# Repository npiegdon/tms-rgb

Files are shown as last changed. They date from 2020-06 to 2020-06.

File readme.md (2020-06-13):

# TMS-RGB #

## An RGB mod for systems using TMS9928A and TMS9929A graphics ##

This small adapter board can unlock the potential of many 8-bit systems from the 1980's including the Colecovision, SG-1000, SC-3000, TI-99/4, and more.

This solution introduces zero latency, works in NTSC or PAL systems, doesn't require any tuning, and can be installed easily.  TMS-RGB was developed in 2020 and solves all known issues found in previous TMS992xA mods of this kind.

Visit [https://tms-rgb.com](https://tms-rgb.com) for more information.

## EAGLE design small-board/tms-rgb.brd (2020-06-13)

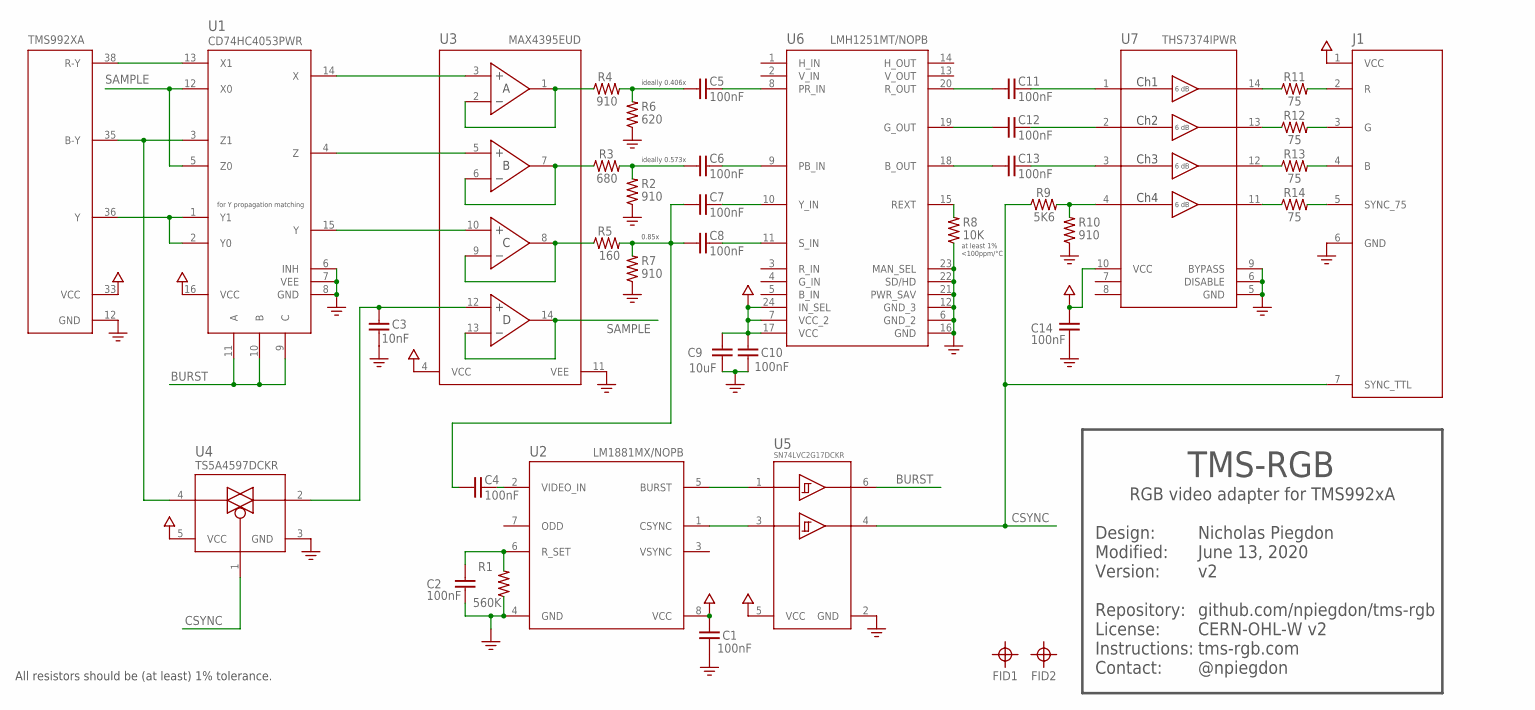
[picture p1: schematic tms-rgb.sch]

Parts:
C1, C2, C4, C5, C6, C7, C8, C10, C11, C12, C13, C14: 100nF; C0603
C3: 10nF; C0603
C9: 10uF; C1206
FID1, FID2: FIDUCIAL
J1: Pads; PADS
R1: 560K; R0603
R2, R4, R7, R10: 910; R0603
R3: 680; R0603
R5: 160; R0603
R6: 620; R0603
R8: 10K; R0603
R9: 5K6; R0603
R11, R12, R13, R14: 75; R0603
U1: CD74HC4053PWR; CD74HC4053
U2: LM1881MX/NOPB; LM1881
U3: MAX4395EUD; MAX4395
U4: TS5A4597DCKR; DCK5
U5: SN74LVC2G17DCKR; DCK6
U6: LMH1251MT/NOPB; LMH1251
U7: THS7374IPWR; THS7374
U100: TMS992XA

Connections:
B: J1.4 (B), R13.2
B-Y: U1.3 (Z1), U4.4 (NC), U100.35 (B-Y)
BURST: U1.9 (C), U1.10 (B), U1.11 (A), U5.6 (1Y)
CSYNC: J1.7 (SYNC_TTL), R9.1, U4.1 (IN), U5.4 (2Y)
G: J1.3 (G), R12.2
GND: C1.2, C2.2, C3.2, C9.2, C10.2, C14.2, J1.6 (GND), R1.1, R2.1, R6.1, R7.1, R8.1, R10.1, U1.6 (INH), U1.7 (VEE), U1.8 (GND), U2.4 (GND), U3.11 (VEE), U4.3 (GND), U5.2 (GND), U6.6 (GND_2), U6.12 (GND_3), U6.16 (GND), U6.21 (PWR_SAV), U6.22 (SD/HD), U6.23 (MAN_SEL), U7.5 (GND), U7.6 (DISABLE), U7.9 (BYPASS), U100.12 (GND)
HOLD: C3.1, U3.12 (D+), U4.2 (COM)
MX_B: U1.4 (Z), U3.5 (B+)
MX_R: U1.14 (X), U3.3 (A+)
MX_Y: U1.15 (Y), U3.10 (C+)
unnamed: R4.1, U3.1 (A), U3.2 (A-)
unnamed: R3.1, U3.6 (B-), U3.7 (B)
unnamed: R5.1, U3.8 (C), U3.9 (C-)
unnamed: U2.5 (BURST), U5.1 (1A)
unnamed: U2.1 (CSYNC), U5.3 (2A)
unnamed: C2.1, R1.2, U2.6 (R_SET)
unnamed: R8.2, U6.15 (REXT)
unnamed: R14.1, U7.11 (CH4OUT)
unnamed: R9.2, R10.2, U7.4 (CH4IN)
unnamed: R13.1, U7.12 (CH3OUT)
unnamed: R12.1, U7.13 (CH2OUT)
unnamed: R11.1, U7.14 (CH1OUT)
unnamed: C4.2, U2.2 (VIDEO_IN)
unnamed: C5.2, U6.8 (PR_IN)
unnamed: C6.2, U6.9 (PB_IN)
unnamed: C8.2, U6.11 (S_IN)
unnamed: C7.2, U6.10 (Y_IN)
unnamed: C11.1, U6.20 (R_OUT)
unnamed: C12.1, U6.19 (G_OUT)
unnamed: C13.1, U6.18 (B_OUT)
unnamed: C11.2, U7.1 (CH1IN)
unnamed: C12.2, U7.2 (CH2IN)
unnamed: C13.2, U7.3 (CH3IN)
R: J1.2 (R), R11.2
R-Y: U1.13 (X1), U100.38 (R-Y)
S75: J1.5 (SYNC_75), R14.2
SAMPLE: U1.5 (Z0), U1.12 (X0), U3.13 (D-), U3.14 (D)
SC_B: C6.1, R2.2, R3.2
SC_R: C5.1, R4.2, R6.2
SC_Y: C4.1, C7.1, C8.1, R5.2, R7.2
VCC: C1.1, C9.1, C10.1, C14.1, J1.1 (VCC), U1.16 (VCC), U2.8 (VCC), U3.4 (VCC), U4.5 (VCC), U5.5 (VCC), U6.7 (VCC_2), U6.17 (VCC), U6.24 (IN_SEL), U7.10 (VCC), U100.33 (VCC)
Y: U1.1 (Y1), U1.2 (Y0), U100.36 (Y)

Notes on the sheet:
Nicholas Piegdon June 13, 2020 v2 github.com/npiegdon/tms-rgb CERN-OHL-W v2 tms-rgb.com @npiegdon
Design: Modified: Version: Repository: License: Instructions: Contact:
RGB video adapter for TMS992xA
TMS-RGB
at least 1% <100ppm/°C
All resistors should be (at least) 1% tolerance.
for Y propagation matching
ideally 0.406x
ideally 0.573x
0.85x

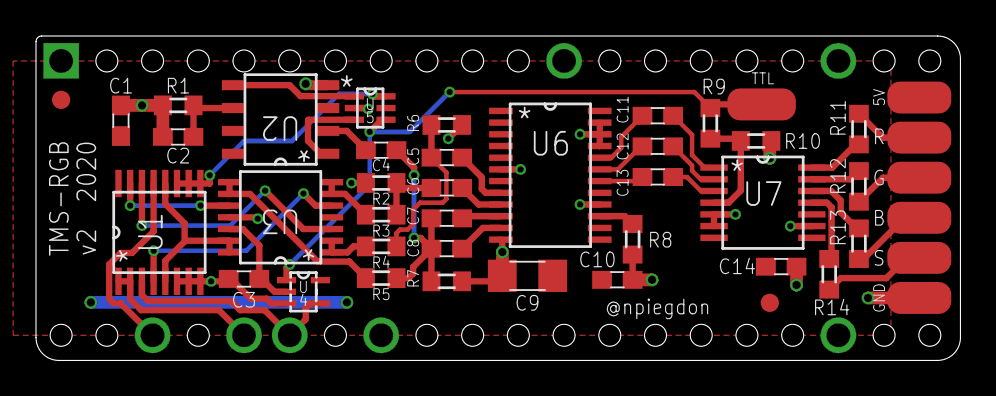
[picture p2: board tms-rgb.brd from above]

Board: 2 copper layers, 51.4 x 18.0 mm, 39 parts (1 on the bottom side), 42 nets.

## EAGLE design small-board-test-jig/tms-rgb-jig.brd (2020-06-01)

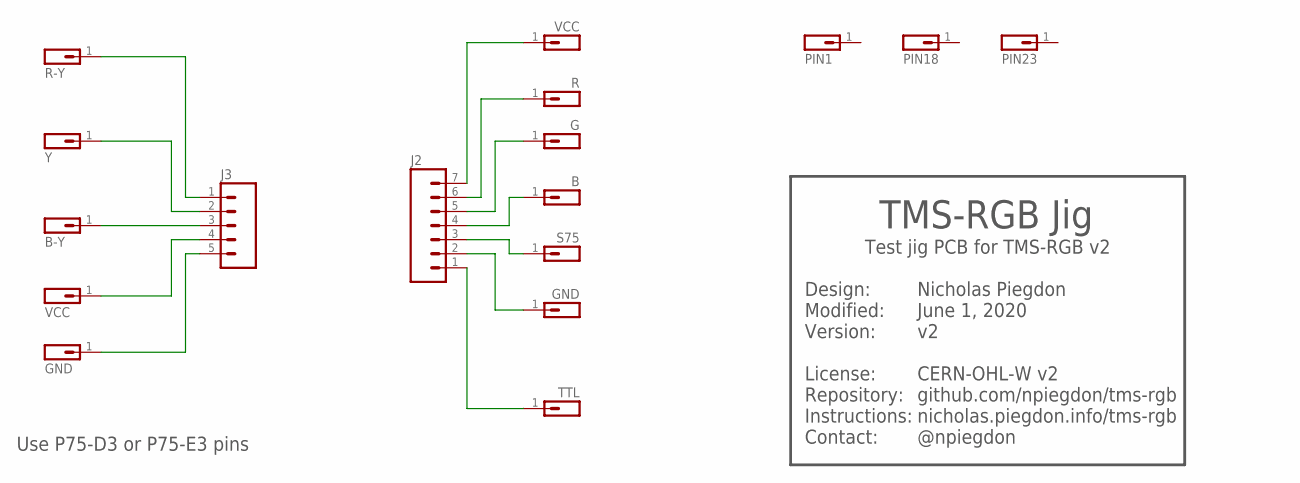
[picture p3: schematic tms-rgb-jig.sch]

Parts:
J2: CONN_07; 1X07
J3: CONN_05; 1X05
J4: R-Y; POGO
J5: B-Y; POGO
J6: Y; POGO
J7, J9: VCC; POGO
J8, J14: GND; POGO
J10: R; POGO
J11: G; POGO
J12: B; POGO
J13: S75; POGO
J15: TTL; POGO
J16: PIN1; POGO
J17: PIN18; POGO
J18: PIN23; POGO

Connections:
unnamed: J3.1, J4.1
unnamed: J3.2, J6.1
unnamed: J3.3, J5.1
unnamed: J3.4, J7.1
unnamed: J3.5, J8.1
unnamed: J2.7, J9.1
unnamed: J2.6, J10.1
unnamed: J2.5, J11.1
unnamed: J2.4, J12.1
unnamed: J2.3, J13.1
unnamed: J2.2, J14.1
unnamed: J2.1, J15.1

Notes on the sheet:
Nicholas Piegdon June 1, 2020 v2 CERN-OHL-W v2 github.com/npiegdon/tms-rgb nicholas.piegdon.info/tms-rgb @npiegdon
Design: Modified: Version: License: Repository: Instructions: Contact:
Test jig PCB for TMS-RGB v2
TMS-RGB Jig
Use P75-D3 or P75-E3 pins

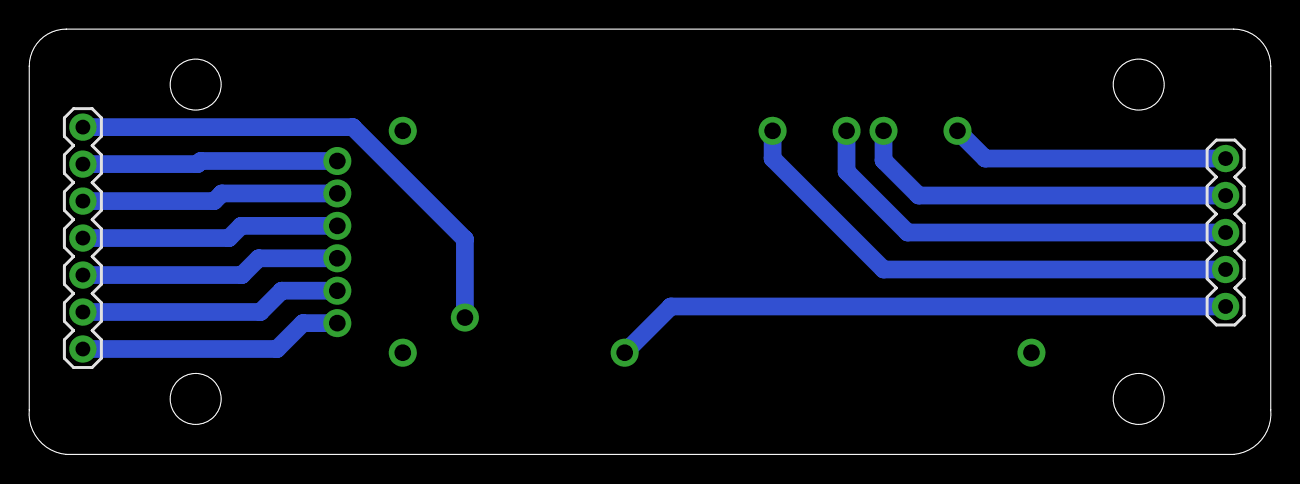
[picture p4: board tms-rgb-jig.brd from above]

Board: 2 copper layers, 85.3 x 29.2 mm, 17 parts (0 on the bottom side), 12 nets.

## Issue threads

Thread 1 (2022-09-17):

What software is needed to open the brd and sch file?

dproldan, 2022-09-17:
For board manufacturing,  three things are needed:  GERBER, BOM and CENTROID.
I couldn't find them anywhere and thought of extracting them from the provided files,  but Kicad fails and no indication of the software used to design this project is given.
 Which software did you use?  Thanks for your hard work and for sharing it!

hanshuebner, 2022-09-17:
The board was designed with [Eagle](https://www.autodesk.com/products/eagle/free-download).  I've successfully generated Gerbers and ordered them from JLCPCB, but that was a long time ago and I don't have the files anymore.

npiegdon, 2022-09-17:
Yep, it's an Eagle project.  (And KiCAD has a pretty good Eagle importer these days, now that you know what to look for.)

You can skip that step completely and just grab the zip with the pre-made Gerbers from the asset list on the [Releases](https://github.com/npiegdon/tms-rgb/releases) page.

Closed 2022-09-17.

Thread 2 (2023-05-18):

Correction needed for SG-1000 and TI-99/4A

leonkiriliuk, 2023-05-18:
The SG-1000 and TI-99/4A use the TMS9918A VDP.  This VDP is missing the video signal on pins 35, 36 and 38 that the TMS-RGB project uses to generate the RGB signal.  The only viable solution to get RGB out of a TMS9918A based device is a complete VDP replacement using a modern FPGA based solution (e.g. F18a or tn9k_f18a projects)

I suggest SG-1000 and TI-99/4A be removed from the docs (and website) to reduce end user confusion.

npiegdon, 2023-05-20:
> The only viable solution to get RGB out of a TMS9918A based device is a complete VDP replacement...

For the TI-99/4A, you can just swap over to a TMS9928A and add three resistors.  Someone in the community wrote a guide, [here](https://forums.atariage.com/topic/310368-rgb-mod-explanation/page/2/#comment-4626296).  I've been planning to add links in the relevant places to show that it's not especially involved to perform that switch (and maybe a few asterisks to mention it includes a VDP swap).

I haven't seen anyone do the same with an SG-1000 yet, so I agree it should probably be removed until it has been demonstrated.

hanshuebner, 2023-05-20:
I can confirm that tms-rgb works perfectly in an European TI-99/4A.

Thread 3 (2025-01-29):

Sega SC-3000

lazaj, 2025-01-29:
I installed a TMS-RGB V2 on a SEGA SC-3000 PAL, and I thought I could remove the original RGB board. However, without the original RGB board, I get no video signal on the TMS-RGB V2. Is this normal ?
I thought the TMS-RGB was retrieving the signals from the TMS and providing an RGB output.

npiegdon, 2025-01-30:
The TMS-RGB board is *almost* all the circuitry you need.  It does rely on a tiny bit being provided from the original system.  In particular, neither the "VDP crystal" nor the source-follower pull-downs are included.  They're expected to be provided by the host system.  (See section 3.4.2 / page 3-6 of the [TMS99xx datasheet](https://wiki.console5.com/tw/images/b/b7/TMS9918A-TMS9928A-TMS9929A_Video_Display_Processors.pdf).  It's a little strange that in the text they recommend 330ohm for the pull-downs but in the diagrams they show 470ohm.)

Do you know if the SC-3000's RGB board provided those pull-downs or the clock signal?

lazaj, 2025-02-10:
The "VDP crystal" is installed on the main PCB for the SEGA SC-3000 PAL but the 3 pulldown resistors are installed on the "RGB board". They are 470ohm.
I am currently working on making brand new PCB for the SEGA SC-3000 PAL (like RE-Amiga project).
All the consoles I restore are not reliable over time due to the PCBs. I will run tests to integrate these three resistors to get rid of the “RGB” board if a TMS-RGB is used.

npiegdon, 2025-02-10:
That sounds like it'll be a good workaround.

I wasn't able to include those on the TMS-RGB board due to the "drop-in" nature of the mod.  A second crystal or second set of pulldowns would have caused conflicts with a system's other video outputs.  An adapter board for new TMS99xx integrations would be able to include these, but TMS-RGB isn't that, hehe.

Let me know how it goes.  (In the meantime, is that enough information to close this?  Or did you want to see it working completely first?)

Closed 2025-02-10.

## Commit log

2020-05-17 Initial commit; v1 release
    [tms-rgb-jig.brd, tms-rgb-jig.sch, tms-rgb.brd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]
2020-05-18 Exclude output pads from stencil
    [tms-rgb.brd, tms-rgb.sch]
2020-05-21 Nudged C4 on the schematic
    It's the sample-and-hold cap but its position (near the SPST instead of the op-amp) didn't reflect that clearly.
    [tms-rgb.brd, tms-rgb.sch]
2020-05-22 A few more solderable holes
    That should make mounting it a little stronger. And now pin 1 on the VDP is indicated on both sides with a square through-hole.
    [tms-rgb.brd, tms-rgb.sch]
2020-05-22 Major layout rework for v2
    [tms-rgb.brd, tms-rgb.sch]
2020-05-22 Named a few signals
    And bridged a distant VCC fill
    [tms-rgb.brd, tms-rgb.sch]
2020-05-23 Better label placement
    Still not great, but maybe a little more usable.
    [tms-rgb.brd]
2020-06-01 More than 100 improvements
    Nearly all of which were suggested by MrPix from the AtariAge forums to improve the electrical characteristics of the board.
    [tms-rgb.brd, tms-rgb.sch]
2020-06-01 Update jig for v2
    [tms-rgb-jig.brd, tms-rgb-jig.sch]
2020-06-02 Updated voltage dividers
    Now we consume around 15mA less with no discernible change to the image.
    [tms-rgb.brd, tms-rgb.sch]
2020-06-13 Updated instructions URL
    The new place is https://tms-rgb.com
    [tms-rgb.brd, tms-rgb.sch]
